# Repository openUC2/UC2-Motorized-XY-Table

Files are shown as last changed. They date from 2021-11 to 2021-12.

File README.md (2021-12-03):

<p align="left">

</p>

# openUC2 *Motorized XY Table*
---

__keywords__: Stepper motors, Arduino, Python, Freecad, 3D printing

The goal of this project is to convert a manual microscope stage into a motorized one that can be used with the UC2 system.
The stage is controlled through a common GRBL (i.e. 3D printer/CNC) interface and also integrates into the [ImSwitch](https://github.com/beniroquai/ImSwitch/tree/master/imswitch) software to control complex microscopy setups.
The precision of displacement approaches the micrometer. 
This repo is a fork from the [SonyCSLParis](https://github.com/SonyCSLParis/Motorized-stage) group.

Curious to see what this looks like? Keep scrolling!

<p align="center">
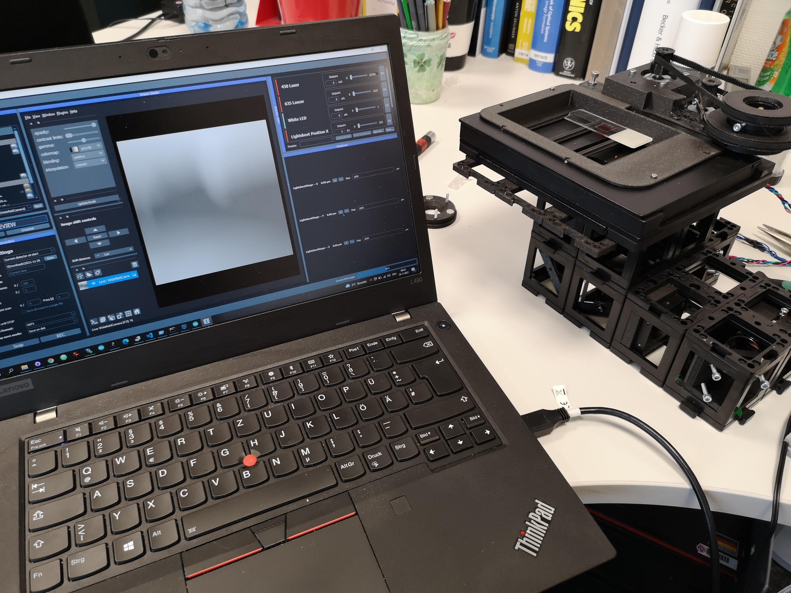
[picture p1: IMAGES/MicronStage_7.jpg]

</p>

All necessary parts besides the motors and the stage can be 3D printed. The overall price is ~200€.

***Features:***

The knobs initially used to manually move the platform are linked to motors via 2 belt-pulley systems (X and Y displacements). One removable part of the platform is replaced by a 3D-printed part that allows to fix the two motors. The pulleys are also 3D-printed to fit on the knobs. 

* Interact with it using GRBL/GCode
* large-scale microscopy slide scanning 
* easy to build 
* simple to automate 
* 

## In-Action

*The stage in action.*

<p align="center">

</p>

# Software

The stage is drive by 2 NEMA 17 stepper motors. For this we use a simple Arduino + CNC Shield v3. We don't want to specify the correct usage of the code here as there are many tutorials for how to interact with stepper motors and Arduino through e.g. Python. A more in-depth tutorial can be found in our [UC2-Hi2 APP](https://github.com/openUC2/UC2-Hi2) that makes use of the Makerbase MKS board and a customized PYTHON Interface. 
If you need assistance, don't hesitate to reach out to us! 

# Hardware

Below we describe how the device can be build and assembled in order to replicate the whole system as shown in the rendering above. One needs additional parts that can be found in the core [openUC2 repository](https://github.com/bionanoimaging/UC2-GIT).

## Bill of material

Below you will find all components necessary to build this device

### 3D printing files

All these files need to be printed. We used a Prusa i3 MK3 using PLA Prusament (Galaxy Black) at layer height x.x mm and infill xx%.

All files can be found in the folder [STL]

<p align="center">
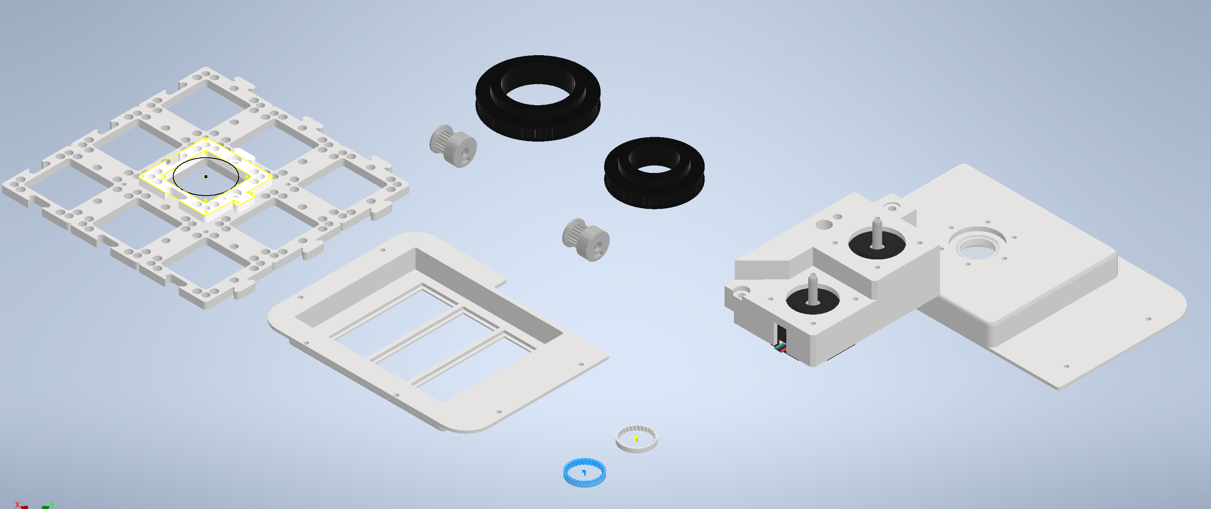
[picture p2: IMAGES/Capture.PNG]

</p>

|  Type | Details  |  Price | Link  | IMAGE |
|---|---|---|---|---|
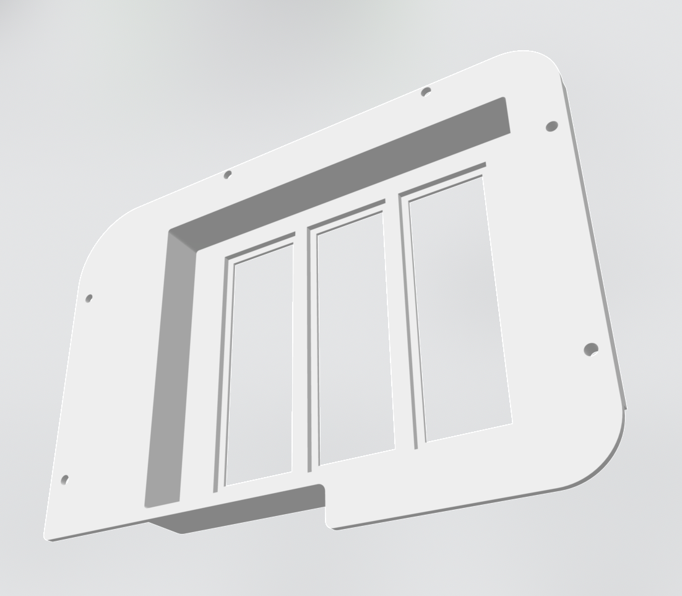
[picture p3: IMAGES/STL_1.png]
| Sample inset |  This can hold three standard sample slides |  1,00 € | [Part.stl](./STL/)  |   |
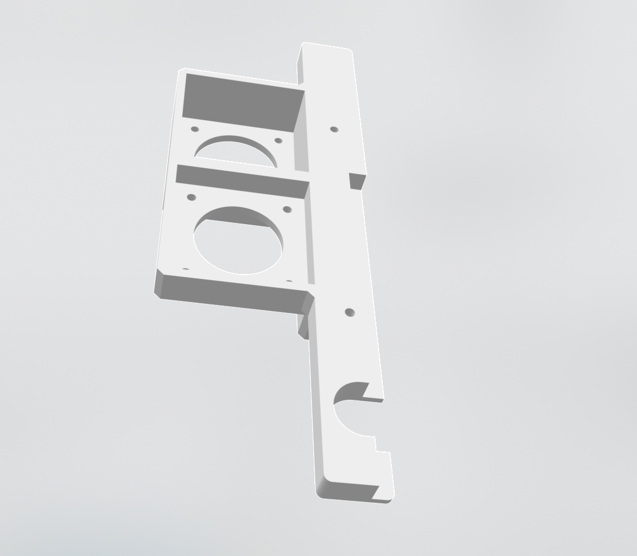
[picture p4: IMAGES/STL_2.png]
| Motor mount |  This holds the two NEMA 17 stepper motors |  1,00 € | [Part.stl](./STL/)  |   |
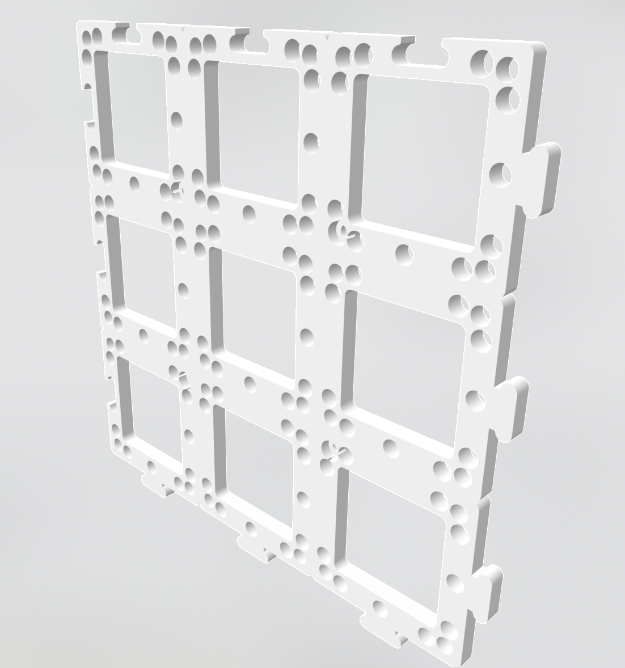
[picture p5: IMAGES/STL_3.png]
| UC2 mount |  This mounts the stage on the cubes |  1,00 € | [Part.stl](./STL/l)  |   |
| Gear Large | For the belt |  1,00 € | [Part.stl](./STL/)  | |
| Gear small |  For the belt |  1,00 € | [Part.stl](./STL/)  |  |
| 2x Pulley  |  For the belt |  1,00 € | [Part.stl](./STL/)  |  |

Fully assembled:
<p align="center">
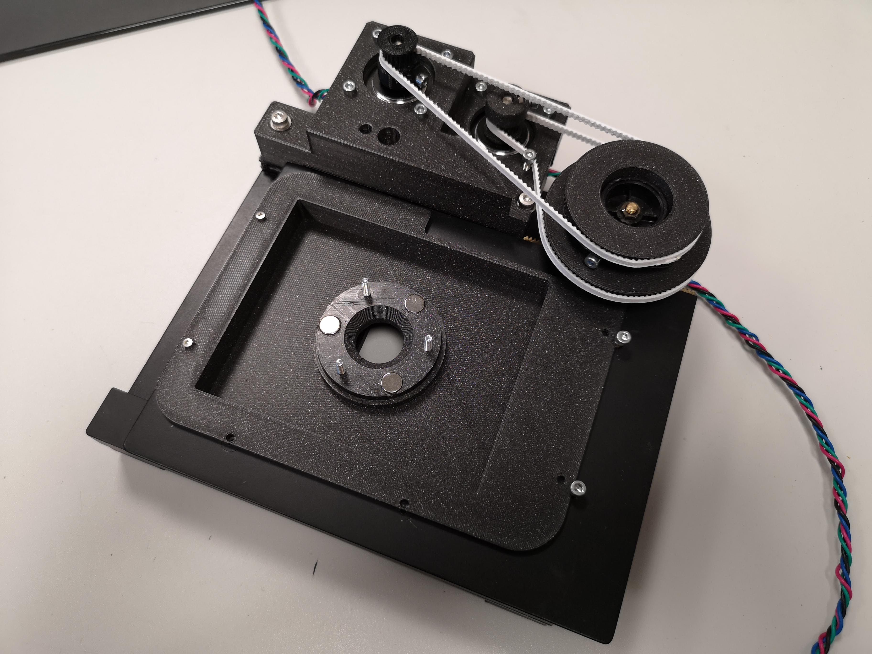
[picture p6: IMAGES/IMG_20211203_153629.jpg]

</p>

***OPTIONAL***: The GT2 timing belts can be printed using TPU/ninjaflex material.

### Additional parts
This is used in the current version of the setup

|  Type | Details  |  Price | Link  |
|---|---|---|---|
| Microscopy XY table |  |  55€ + Shiping  | [Aliexpress](https://de.aliexpress.com/item/32850719102.html)  |
| Microscopy XY table (German Alternative) |  |  255€ + Shiping  | [Optik Pro](https://www.optik-pro.de/fuer-stereomikroskope/euromex-xy-tisch-dz-9020-185x145mm-dz-reihe/p,47040)  |
| 2x Pancake NEMA 17 motors  |  9€ + Shiping  | [Ebay](https://www.ebay.de/itm/392553834244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)  |
| Motor belt GT2 |2 |1€|[Phidgets](https://www.phidgets.com/?tier=2&catid=42&pcid=35) |
| Motor pulley 20 teeth/5mm bore |2 | 1€ |[Phidgets](https://www.phidgets.com/?tier=2&catid=42&pcid=35) | |
| Arduino + CNC Shield v3 + A4988 Drivers + 12 V supply  |2 | 20€ |[roboterbausatz.de]() | |
| Connection wires | | |  
| Screws M2, M3 | | |  
| 3D printer |

### Design files

All files are in the [INVENTOR](./INVENTOR) folder.

### Assembly of the DEVICE

***1.*** *Remove the ring on the bottom surface (some screws) and add the UC2 baseplate adapter with M3 screws*

<p align="center">
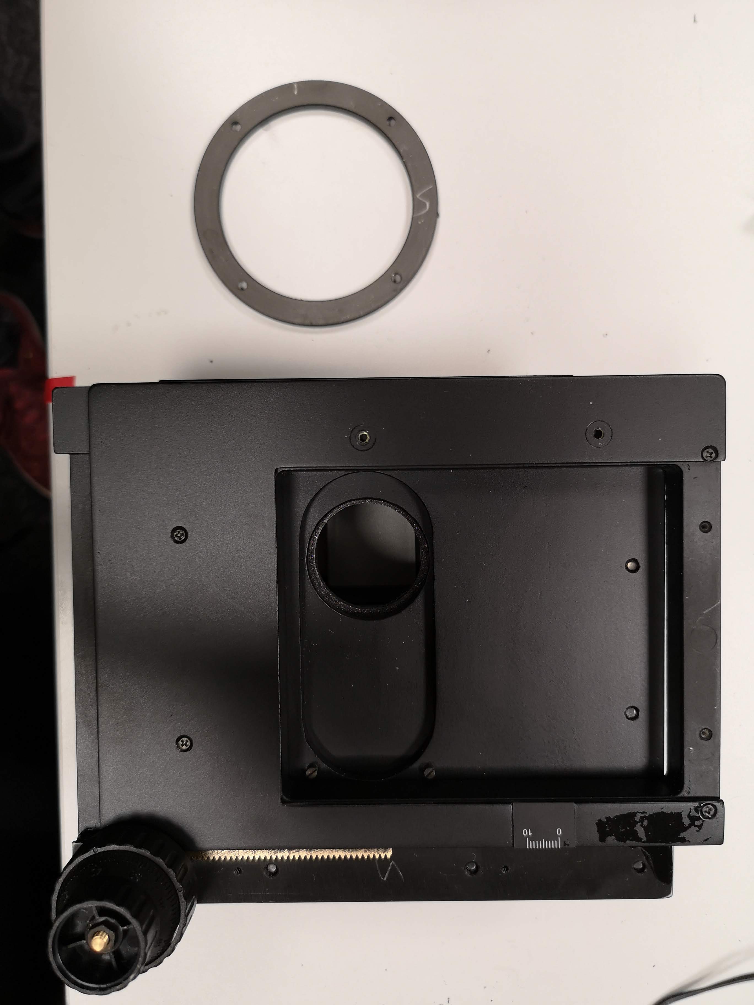
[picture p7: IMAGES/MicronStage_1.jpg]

</p>

<p align="center">
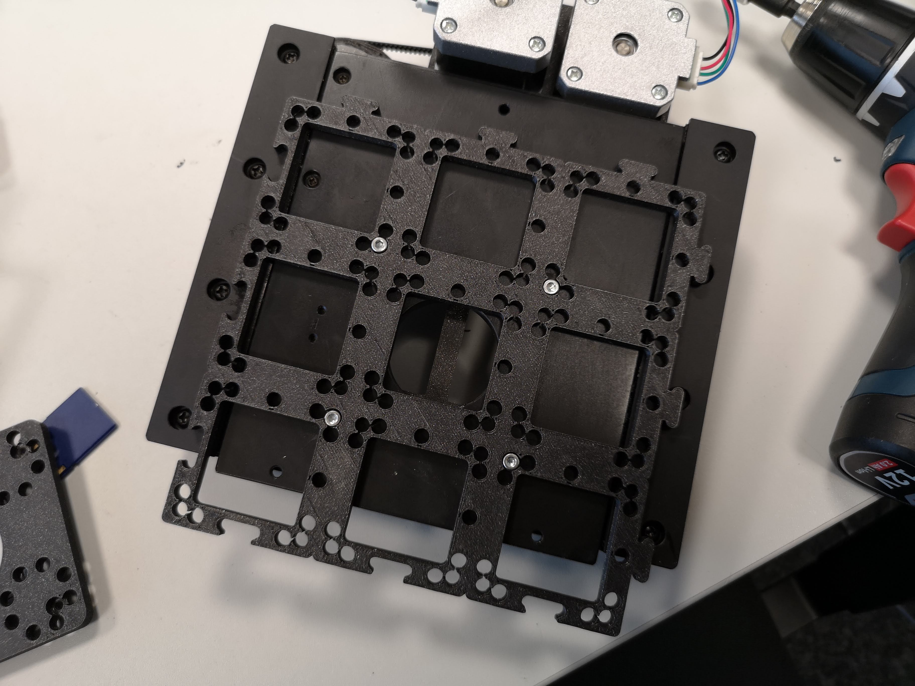
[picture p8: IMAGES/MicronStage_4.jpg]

</p>

***2.*** *Remove the stickers for the markers and unscrew the metal bar*

<p align="center">
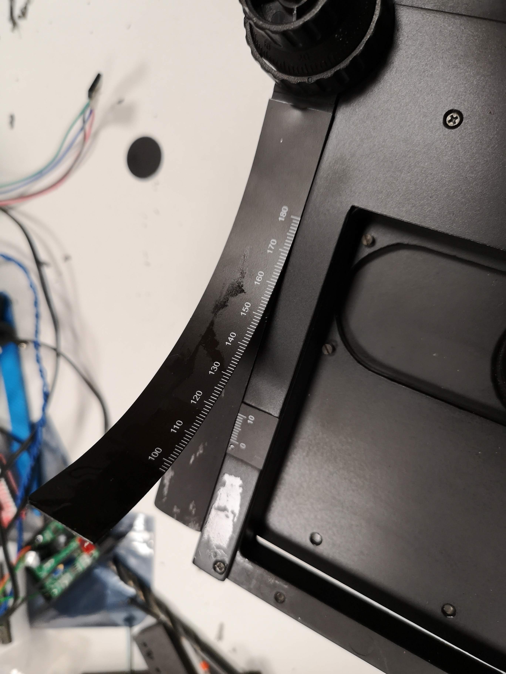
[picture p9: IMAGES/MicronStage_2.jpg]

</p>

<p align="center">
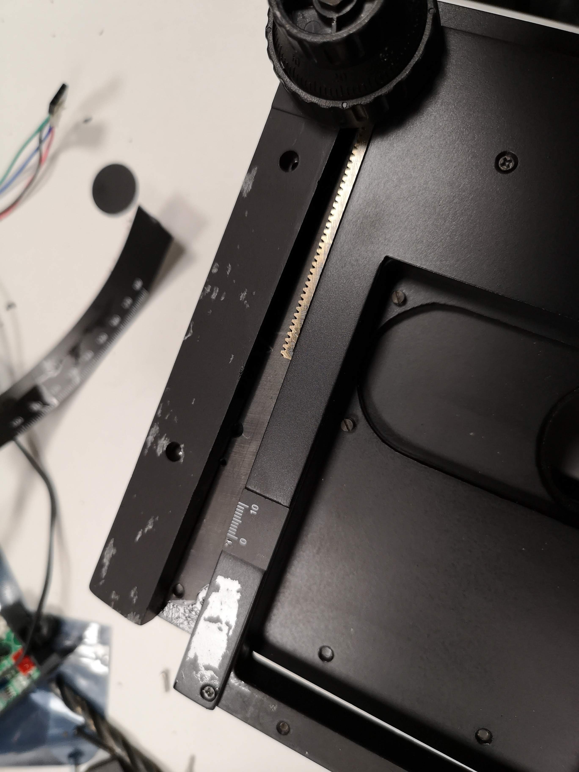
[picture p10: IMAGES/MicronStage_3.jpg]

</p>

***3.*** *Add the motors to the motor holder with M3 screws*

***PICTURES MISSING***

***4.*** *Add motor bar to the stage with M2 and M3 screws*

***PICTURES MISSING***

***5.*** *Add gears to motors and knobs*

***PICTURES MISSING***

***6.*** *Cut the belt and glue ends together to match the length properly using fast glue*

<p align="center">
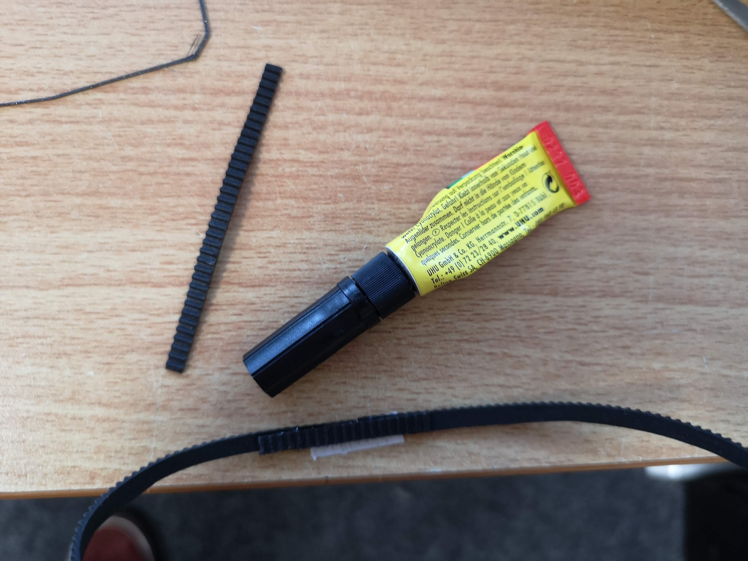
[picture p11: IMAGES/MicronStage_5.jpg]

</p>

***7.*** *Done*

<p align="center">
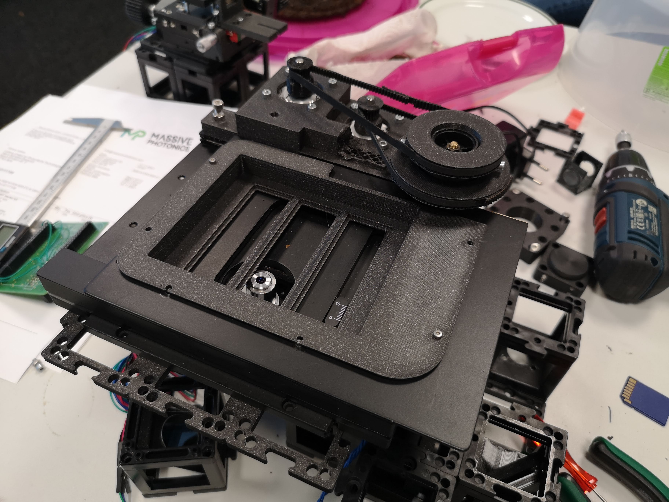
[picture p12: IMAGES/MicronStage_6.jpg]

</p>

## Showcase

Automation of a manual microscope stage

<p align="center">
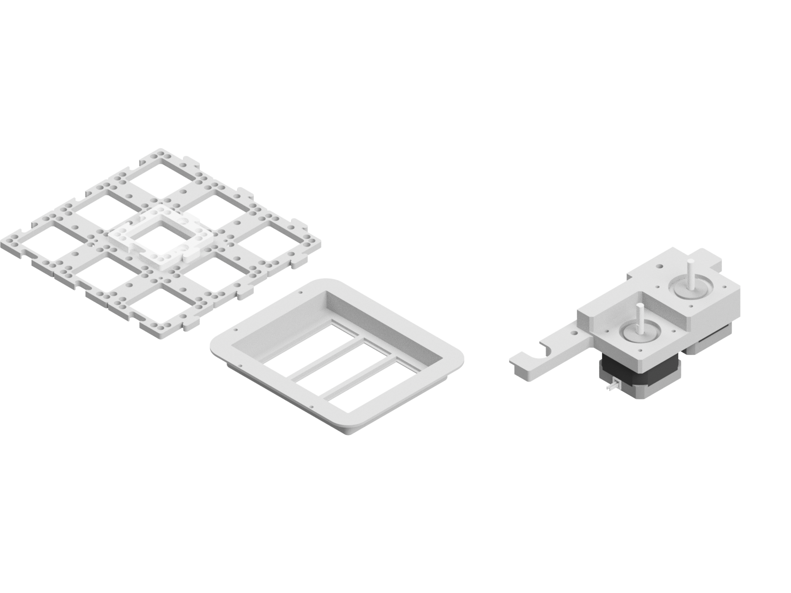
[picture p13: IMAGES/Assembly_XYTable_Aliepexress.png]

</p>

## Get Involved

This project is open so that anyone can get involved. You don't even have to learn CAD designing or programming. Find ways you can contribute in  [CONTRIBUTING](https://github.com/openUC2/UC2-GIT/blob/master/CONTRIBUTING.md)

## License and Collaboration

This project is open-source and is released under the CERN open hardware license. Our aim is to make the kits commercially available.
We encourage everyone who is using our Toolbox to share their results and ideas, so that the Toolbox keeps improving. It should serve as a easy-to-use and easy-to-access general purpose building block solution for the area of STEAM education. All the design files are generally for free, but we would like to hear from you how is it going.

You're free to fork the project and enhance it. If you have any suggestions to improve it or add any additional functions make a pull-request or file an issue.

Please find the type of licenses [here](https://github.com/openUC2/UC2-GIT/blob/master/License.md)

REMARK: All files have been designed using Autodesk Inventor 2019 (EDUCATION)

## Collaborating
If you find this project useful, please like this repository, follow us on Twitter and cite the webpage! :-)

-------

***FROM THE ORIGINAL FORK:***

# Results 

In the end we were able to control the movement of the stage to go from one trap to the following one. The following animation shows a trap and its neighbour appearing one after the other in the center of the camera.

<p align="center">

</p>

<p align="center">
Credits: Léa Pinon and Jacques Fattacioli for the microfluidic set-up (ENS, IPGG), Thomas Le Saux and Aliénor Lahlou for the imaging set-up (ENS, Sony CSL)
</p>  

By using the EasyDriver we could rotate each motor by one microstep. In the end the set-up enabled us to reach a minimal movement of 1,95 μm along the **x** axis and of 0,05 μm along the **y** axis.

In order to estimate the quality of our set-up, we measured its precision using the registration method which calculates the spatial correlation between two successive IMAGES.

On the one hand the analyses of these results shows that the stage moves linearly along the **y** axis as expected. We concluded that our set-up was of good quality for this direction.

<p align="center">

</p>

On the other hand we discovered that the movement along the **x** axis is flawed. Indeed when moving the stage along this axis we regularly measure a small unwanted movement along the **y** axis. This shortcoming leads to imprecise movement along the **x** axis, and it seems to come from the mechanics of the manual platform.

<p align="center">

</p>

For the **x**-axis we measured that one turn of the knob moves the stage by 2,5 cm. In the case of the **x** axis the 17HM08-1204S stepper motor has 3200 microsteps per revolution and the master pulley has 20 teeth. Thus we calculated that the **x**-axis slave pulley needed to have 32 teeth. Such a little number of teeth leads to modeling issues.

Thus we decided to design an 80 teeth slave pulley for the **x**-axis knob. This leads to a higher precision : when the stepper motor rotates by 1 microstep, the stage moves by 1,95 μm along the **x** axis (with a simple Nema 17 motor)

## Assembly

In order to keep things simple we decided to control both stepper motors with one Arduino UNO microcontroller. We still had to use one EasyDriver microcontroller for each stepper motor. We used [Brian Schmalzhaus' example](https://www.schmalzhaus.com/EasyDriver/Examples/EasyDriverExamples.html) running multiple stepper motors. The set-up can be seen in the following diagram. As we wanted precise movements, we enabled microstepping control for both motors by adding connections between the MS1 and MS2 pins and the ground for each EasyDriver microcontroller.

<p align="center">
<img src="IMAGES/image_from_schmalzhaus.png" width=500"/>
</p>  

<p align="center">
<a href=https://www.schmalzhaus.com/EasyDriver/Examples/EasyDriverExamples.html>source</a>
</p>  

## License

This project is licensed under the [GNU General Public License v3.0](https://tldrlegal.com/license/gnu-general-public-license-v3-(gpl-3))

## Contacts
If you have questions you can contact Ali Ruyer-Thompson (ali.ruyer--thompson :email: ens.psl.eu) or Aliénor Lahlou (alienor.lahlou :email: ens.psl.eu)

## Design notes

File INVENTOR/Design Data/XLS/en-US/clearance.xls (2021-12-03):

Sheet: Ansi Unified Screw Threads
I | Sort Order -1
Fastener Type | Size | Shaft Diameters |  |  | Head Dimensions
 |  | Close | Normal | Loose | Diameter | Depth/Angle | Head Type
Flat Head Machine Screw (82) | #0 | 0.0635 | 0.07 | 0.073 | 0.119 | 82 | 2
Flat Head Machine Screw (82) | #1 | 0.076 | 0.081 | 0.089 | 0.146 | 82 | 2
Flat Head Machine Screw (82) | #2 | 0.089 | 0.096 | 0.1065 | 0.172 | 82 | 2
Flat Head Machine Screw (82) | #3 | 0.104 | 0.11 | 0.12 | 0.199 | 82 | 2
Flat Head Machine Screw (82) | #4 | 0.116 | 0.1285 | 0.136 | 0.225 | 82 | 2
Flat Head Machine Screw (82) | #5 | 0.1285 | 0.136 | 0.154 | 0.252 | 82 | 2
Flat Head Machine Screw (82) | #6 | 0.144 | 0.1495 | 0.1695 | 0.279 | 82 | 2
Flat Head Machine Screw (82) | #8 | 0.1695 | 0.177 | 0.1935 | 0.332 | 82 | 2
Flat Head Machine Screw (82) | #10 | 0.196 | 0.201 | 0.221 | 0.385 | 82 | 2
Flat Head Machine Screw (82) | #12 | 0.221 | 0.228 | 0.246 | 0.438 | 82 | 2
Flat Head Machine Screw (82) | 1/4 | 0.257 | 0.266 | 0.2812 | 0.507 | 82 | 2
Flat Head Machine Screw (82) | 5/16 | 0.323 | 0.332 | 0.3437 | 0.635 | 82 | 2
Flat Head Machine Screw (82) | 3/8 | 0.386 | 0.397 | 0.4062 | 0.762 | 82 | 2
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

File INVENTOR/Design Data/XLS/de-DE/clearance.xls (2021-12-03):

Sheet: ANSI UST
I | Reihenfolge -1
Schraubentyp | Größe | Wellendurchmesser |  |  | Schraubenkopfbemaßungen
 |  | Schließen | Normal | Grob | Durchmesser | Tiefe/Winkel | Schraubenkopftyp
Flachkopfmaschinenschraube (82) | #0 | 0.0635 | 0.07 | 0.073 | 0.119 | 82 | 2
Flachkopfmaschinenschraube (82) | #1 | 0.076 | 0.081 | 0.089 | 0.146 | 82 | 2
Flachkopfmaschinenschraube (82) | #2 | 0.089 | 0.096 | 0.1065 | 0.172 | 82 | 2
Flachkopfmaschinenschraube (82) | #3 | 0.104 | 0.11 | 0.12 | 0.199 | 82 | 2
Flachkopfmaschinenschraube (82) | #4 | 0.116 | 0.1285 | 0.136 | 0.225 | 82 | 2
Flachkopfmaschinenschraube (82) | #5 | 0.1285 | 0.136 | 0.154 | 0.252 | 82 | 2
Flachkopfmaschinenschraube (82) | #6 | 0.144 | 0.1495 | 0.1695 | 0.279 | 82 | 2
Flachkopfmaschinenschraube (82) | #8 | 0.1695 | 0.177 | 0.1935 | 0.332 | 82 | 2
Flachkopfmaschinenschraube (82) | #10 | 0.196 | 0.201 | 0.221 | 0.385 | 82 | 2
Flachkopfmaschinenschraube (82) | #12 | 0.221 | 0.228 | 0.246 | 0.438 | 82 | 2
Flachkopfmaschinenschraube (82) | 1/4 | 0.257 | 0.266 | 0.2812 | 0.507 | 82 | 2
Flachkopfmaschinenschraube (82) | 5/16 | 0.323 | 0.332 | 0.3437 | 0.635 | 82 | 2
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

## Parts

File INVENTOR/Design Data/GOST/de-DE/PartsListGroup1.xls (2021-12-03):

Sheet: Лист 1
Инв. № подл |  |  |  | Подп. и дата | Взам. инв. № | Инв. № дубл. |  |  | Подп. и дата
Формат | Зона | Поз. | Обозначение |  |  |  | Наименование |  |  |  |  |  | Кол. на исполнение
 |  |  |  |  |  |  |  |  |  |  |  | Лит.
 |  |  |  |  |  |  |  |  |  |  |  | Код
 |  |  |  |  |  |  |  | Изм. | Лист | № докум | Подпись |  | Дата
 |  |  |  |  |  |  |  | Разраб.
 |  |  |  |  |  |  |  | Пров.
 |  |  |  |  |  |  |  | Н.контр
 |  |  |  |  |  |  |  | Утв.
 |  |  |  |  |  |  |  |  |  |  |  |  |  | Копировал

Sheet: Лист 2
Инв. № подл |  |  |  | Подп. и дата | Взам. инв. № | Инв. № дубл. |  |  | Подп. и дата
Формат | Зона | Поз. | Обозначение |  |  |  | Наименование |  |  |  |  | Кол. на исполнение
 |  |  |  |  |  |  |  | Изм. | Лист | № докум. | Подп. | Дата
 |  |  |  |  |  |  |  |  |  |  |  |  | Копировал
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

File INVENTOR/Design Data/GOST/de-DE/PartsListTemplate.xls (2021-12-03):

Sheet: Лист 1
 | Формат | Зона |  | Поз. |  | Обозначение |  |  |  | Наименование |  |  |  | Кол. | Приме-чание
Подп. и дата
Инв. № дубл.
Взам. инв. №
Подп. и дата
 | Изм. |  | Лист |  | № докум |  | Подпись | Дата
Инв. № подл | Разраб. |  |  |  |  |  |  |  |  |  | Литера |  | Лист |  |  | Листов
 | Пров.
 | Н.контр
 | Утв.
 |  |  |  |  |  |  |  |  | Копировал |  |  | Формат А4

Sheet: Лист 2
 | Формат | Зона |  | Поз. |  | Обозначение |  |  |  | Наименование |  | Кол. | Приме-чание
Подп. и дата
Инв. № дубл.
Взам. инв. №
Подп. и дата
Инв. № подл
 | Изм. |  | Лист |  | № докум. |  | Подп. |  | Дата
 |  |  |  |  |  |  |  | Копировал |  |  | Формат А4
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

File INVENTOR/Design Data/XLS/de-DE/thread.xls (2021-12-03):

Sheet: Inch Tapping Threads
I Q X | Zoll-Blechschraubgewinde |  | Sort Order - 5 |  | External |  |  |  |  |  |  | Internal
 |  |  |  |  |  | Major Dia |  | Pitch Dia |  | Minor Dia |  |  | Minor Dia |  | Pitch Dia |  | Major Dia |  | Tap Drill
Size | Size Suffix | Thread Designation | Custom Thread Designation | TPI | Class | Max | Min | Max | Min | Max | Min | Class | Min | Max | Min | Max | Min | Max | Basic
0.0600 |  | 0-48 | 0-48 | 48 | 2B | 0.0600 | 0.0540 | 0.0480 | 0.0435 | 0.0360 | 0.0330
0.0730 |  | 1-42 | 1-42 | 42 | 2B | 0.0750 | 0.0690 | 0.0620 | 0.0575 | 0.0490 | 0.0460
0.0860 |  | 2-32 | 2-32 | 32 | 2B | 0.0880 | 0.0820 | 0.0760 | 0.0710 | 0.0640 | 0.0600
0.0990 |  | 3-28 | 3-28 | 28 | 2B | 0.1010 | 0.0950 | 0.0880 | 0.0830 | 0.0750 | 0.0710
0.1120 |  | 4-24 | 4-24 | 24 | 2B | 0.1140 | 0.1080 | 0.1000 | 0.0950 | 0.0860 | 0.0820
0.1250 |  | 5-20 | 5-20 | 20 | 2B | 0.1300 | 0.1230 | 0.1120 | 0.1065 | 0.0940 | 0.0900
0.1380 |  | 6-20 | 6-20 | 20 | 2B | 0.1390 | 0.1320 | 0.1215 | 0.1155 | 0.1040 | 0.0990
0.1510 |  | 7-19 | 7-19 | 19 | 2B | 0.1540 | 0.1470 | 0.1345 | 0.1280 | 0.1150 | 0.1090
0.1640 |  | 8-18 | 8-18 | 18 | 2B | 0.1660 | 0.1590 | 0.1440 | 0.1375 | 0.1220 | 0.1160
0.1900 |  | 10-16 | 10-16 | 16 | 2B | 0.1890 | 0.1820 | 0.1650 | 0.1585 | 0.1410 | 0.1350
0.2160 |  | 12-14 | 12-14 | 14 | 2B | 0.2150 | 0.2080 | 0.1895 | 0.1825 | 0.1640 | 0.1570
0.2420 |  | 14-14 | 14-14 | 14 | 2B | 0.2410 | 0.2340 | 0.2130 | 0.2060 | 0.1850 | 0.1780
0.2500 |  | 1/4-14 | 1/4-14 | 14 | 2B | 0.2460 | 0.2370 | 0.2190 | 0.2110 | 0.1920 | 0.1850
0.3125 |  | 5/16-12 | 5/16-12 | 12 | 2B | 0.3150 | 0.3060 | 0.2795 | 0.2710 | 0.2440 | 0.2360
0.3750 |  | 3/8-12 | 3/8-12 | 12 | 2B | 0.3800 | 0.3710 | 0.3445 | 0.3350 | 0.3090 | 0.2990
0.4375 |  | 7/16-10 | 7/16-10 | 10 | 2B | 0.4400 | 0.4290 | 0.3995 | 0.3890 | 0.3590 | 0.3490
0.5000 |  | 1/2-10 | 1/2-10 | 10 | 2B | 0.5040 | 0.4930 | 0.4635 | 0.4530 | 0.4230 | 0.4130

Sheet: Metric Forming Screw Threads
M P X | Metrisch geform. Schraubgewinde |  | Sort Order - 6 |  | External |  |  |  |  |  |  | Internal
 |  |  |  |  |  | Major Dia |  | Pitch Dia |  | Minor Dia |  |  | Minor Dia |  | Pitch Dia |  | Major Dia |  | Tap Drill
Size | Size Suffix | Thread Designation | Custom Thread Designation | Pitch | Class | Max | Min | Max | Min | Max | Min | Class | Min | Max | Min | Max | Min | Max | Basic
1.5 |  | 1.5x0.5 | 1.5x0.5 | 0.5 | 6g | 1.520 | 1.380 | 1.215 | 1.110 | 0.910 | 0.840
1.5 |  | ST1.5x0.5 | ST1.5x0.5 | 0.5 | 6g | 1.520 | 1.380 | 1.215 | 1.110 | 0.910 | 0.840
1.9 |  | 1.9x0.6 | 1.9x0.6 | 0.6 | 6g | 1.900 | 1.760 | 1.570 | 1.465 | 1.240 | 1.170
1.9 |  | ST1.9x0.6 | ST1.9x0.6 | 0.6 | 6g | 1.900 | 1.760 | 1.570 | 1.465 | 1.240 | 1.170
2.2 |  | 2.2x0.8 | 2.2x0.8 | 0.8 | 6g | 2.240 | 2.100 | 1.935 | 1.810 | 1.630 | 1.520
2.2 |  | ST2.2x0.8 | ST2.2x0.8 | 0.8 | 6g | 2.240 | 2.100 | 1.935 | 1.810 | 1.630 | 1.520
2.6 |  | 2.6x0.9 | 2.6x0.9 | 0.9 | 6g | 2.570 | 2.430 | 2.235 | 2.115 | 1.900 | 1.800
2.6 |  | ST2.6x0.9 | ST2.6x0.9 | 0.9 | 6g | 2.570 | 2.430 | 2.235 | 2.115 | 1.900 | 1.800
2.9 |  | 2.9x1 | 2.9x1 | 1 | 6g | 2.900 | 2.760 | 2.540 | 2.420 | 2.180 | 2.080
2.9 |  | 2.9x1.1 | 2.9x1.1 | 1.1 | 6g | 2.900 | 2.760 | 2.540 | 2.420 | 2.180 | 2.080
2.9 |  | ST2.9x1.1 | ST2.9x1.1 | 1.1 | 6g | 2.900 | 2.760 | 2.540 | 2.420 | 2.180 | 2.080
2.9 |  | 2.9x1.3 | 2.9x1.3 | 1.3 | 6g | 2.900 | 2.720 | 2.540 | 2.355 | 1.890 | 1.700
2.9 |  | 2.9x1.4 | 2.9x1.4 | 1.4 | 6g | 2.900 | 2.720 | 2.340 | 2.175 | 1.780 | 1.630
3.3 |  | 3.3x1.3 | 3.3x1.3 | 1.3 | 6g | 3.300 | 3.120 | 2.795 | 2.665 | 2.290 | 2.210
3.3 |  | ST3.3x1.3 | ST3.3x1.3 | 1.3 | 6g | 3.300 | 3.120 | 2.795 | 2.665 | 2.290 | 2.210
3.5 |  | 3.5x1.3 | 3.5x1.3 | 1.3 | 6g | 3.530 | 3.350 | 3.085 | 2.930 | 2.640 | 2.510
3.5 |  | ST3.5x1.3 | ST3.5x1.3 | 1.3 | 6g | 3.530 | 3.350 | 3.085 | 2.930 | 2.640 | 2.510
3.5 |  | 3.5x1.6 | 3.5x1.6 | 1.6 | 6g | 3.530 | 3.350 | 2.920 | 2.755 | 2.310 | 2.160
3.5 |  | 3.5x3.2 | 3.5x3.2 | 3.2 | 6g | 3.530 | 3.310 | 2.800 | 2.600 | 2.070 | 1.890
3.9 |  | 3.9x1.3 | 3.9x1.3 | 1.3 | 6g | 3.910 | 3.730 | 3.415 | 3.250 | 2.920 | 2.770
3.9 |  | ST3.9x1.3 | ST3.9x1.3 | 1.3 | 6g | 3.910 | 3.730 | 3.415 | 3.250 | 2.920 | 2.770
3.9 |  | 3.9x1.6 | 3.9x1.6 | 1.6 | 6g | 3.910 | 3.730 | 3.300 | 3.135 | 2.690 | 2.540
3.9 |  | 3.9x3.2 | 3.9x3.2 | 3.2 | 6g | 3.910 | 3.690 | 3.180 | 2.980 | 2.450 | 2.270
4.2 |  | 4.2x1.4 | 4.2x1.4 | 1.4 | 6g | 4.220 | 4.040 | 3.660 | 3.495 | 3.100 | 2.950
4.2 |  | ST4.2x1.4 | ST4.2x1.4 | 1.4 | 6g | 4.220 | 4.040 | 3.660 | 3.495 | 3.100 | 2.950
4.2 |  | 4.2x1.6 | 4.2x1.6 | 1.6 | 6g | 4.220 | 4.040 | 3.610 | 3.445 | 3.000 | 2.850
4.2 |  | 4.2x3.2 | 4.2x3.2 | 3.2 | 6g | 4.220 | 4.000 | 3.380 | 3.180 | 2.540 | 2.360
4.8 |  | 4.8x1.6 | 4.8x1.6 | 1.6 | 6g | 4.800 | 4.620 | 4.190 | 4.025 | 3.580 | 3.430
4.8 |  | ST4.8x1.6 | ST4.8x1.6 | 1.6 | 6g | 4.800 | 4.620 | 4.190 | 4.025 | 3.580 | 3.430
4.8 |  | 4.8x1.8 | 4.8x1.8 | 1.8 | 6g | 4.800 | 4.620 | 4.065 | 3.885 | 3.330 | 3.150
4.8 |  | 4.8x3.2 | 4.8x3.2 | 3.2 | 6g | 4.800 | 4.580 | 3.960 | 3.760 | 3.120 | 2.940
5.5 |  | 5.5x1.8 | 5.5x1.8 | 1.8 | 6g | 5.460 | 5.280 | 4.815 | 4.635 | 4.170 | 3.990
5.5 |  | ST5.5x1.8 | ST5.5x1.8 | 1.8 | 6g | 5.460 | 5.280 | 4.815 | 4.635 | 4.170 | 3.990
6.3 |  | 6.3x1.8 | 6.3x1.8 | 1.8 | 6g | 6.250 | 6.030 | 5.565 | 5.365 | 4.880 | 4.700
6.3 |  | ST6.3x1.8 | ST6.3x1.8 | 1.8 | 6g | 6.250 | 6.030 | 5.565 | 5.365 | 4.880 | 4.700
8.0 |  | 8x2.1 | 8x2.1 | 2.1 | 6g | 8.000 | 7.780 | 7.100 | 6.885 | 6.200 | 5.990
8.0 |  | ST8x2.1 | ST8x2.1 | 2.1 | 6g | 8.000 | 7.780 | 7.100 | 6.885 | 6.200 | 5.990
9.5 |  | 9.5x2.1 | 9.5x2.1 | 2.1 | 6g | 9.650 | 9.430 | 8.750 | 8.510 | 7.850 | 7.590
9.5 |  | ST9.5x2.1 | ST9.5x2.1 | 2.1 | 6g | 9.650 | 9.430 | 8.750 | 8.510 | 7.850 | 7.590

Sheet: ISO Pipe Threads
M Q | ISO-Rohrgewinde |  | Sort Order - 9 |  | External |  |  |  |  |  |  | Internal
 |  |  |  |  |  | Major Dia |  | Pitch Dia |  | Minor Dia |  |  | Minor Dia |  | Pitch Dia |  | Major Dia |  | Tap Drill | Thread Depth | Thread Runouts
Size | Size Suffix | Thread Designation | Custom Thread Designation | TPI | Class | Max | Min | Max | Min | Max | Min | Class | Min | Max | Min | Max | Min | Max | Basic
7.723 |  | G7.723x0.907 | G 1/16 | 28 | A | 7.723 | 7.509 | 7.142 | 7.035 | 6.561 |  |  | 6.561 | 6.834 | 7.142 | 7.249 | 7.723 |  | 1.5875 | 15.446 | 4.5000
7.723 |  | G7.723x0.907 | G 1/16 | 28 | B | 7.723 | 7.509 | 7.142 | 6.928 | 6.561
9.728 |  | G9.728x0.907 | G 1/8 | 28 | A | 9.728 | 9.514 | 9.147 | 9.040 | 8.566 |  |  | 8.566 | 8.848 | 9.147 | 9.254 | 9.728 |  | 3.1750 | 19.456 | 4.5000
9.728 |  | G9.728x0.907 | G 1/8 | 28 | B | 9.728 | 9.514 | 9.147 | 8.933 | 8.566
13.157 |  | G13.157x1.337 | G 1/4 | 19 | A | 13.157 | 12.907 | 12.301 | 12.176 | 11.445 |  |  | 11.445 | 11.89 | 12.301 | 12.426 | 13.157 |  | 6.3500 | 26.314 | 6.5000
13.157 |  | G13.157x1.337 | G 1/4 | 19 | B | 13.157 | 12.907 | 12.301 | 12.051 | 11.445
16.662 |  | G16.662x1.337 | G 3/8 | 19 | A | 16.662 | 16.412 | 15.806 | 15.681 | 14.950 |  |  | 14.95 | 15.395 | 15.806 | 15.931 | 16.662 |  | 9.5250 | 33.324 | 6.5000
16.662 |  | G16.662x1.337 | G 3/8 | 19 | B | 16.662 | 16.412 | 15.806 | 15.556 | 14.950
20.955 |  | G20.955x1.814 | G 1/2 | 14 | A | 20.955 | 20.671 | 19.793 | 19.651 | 18.631 |  |  | 18.631 | 19.172 | 19.793 | 19.935 | 20.955 |  | 12.7000 | 41.910 | 8.5000
20.955 |  | G20.955x1.814 | G 1/2 | 14 | B | 20.955 | 20.671 | 19.793 | 19.509 | 18.631
22.911 |  | G22.911x1.814 | G 5/8 | 14 | A | 22.911 | 22.627 | 21.749 | 21.607 | 20.587 |  |  | 20.587 | 21.128 | 21.749 | 21.891 | 22.911 |  |  | 45.822 | 8.5000
22.911 |  | G22.911x1.814 | G 5/8 | 14 | B | 22.911 | 22.627 | 21.749 | 21.465 | 20.587
26.441 |  | G26.441x1.814 | G 3/4 | 14 | A | 26.441 | 26.157 | 25.279 | 25.137 | 24.117 |  |  | 24.117 | 24.658 | 25.279 | 25.421 | 26.441 |  | 15.8750 | 52.882 | 8.5000
26.441 |  | G26.441x1.814 | G 3/4 | 14 | B | 26.441 | 26.157 | 25.279 | 24.995 | 24.117
30.201 |  | G30.201x1.814 | G 7/8 | 14 | A | 30.201 | 29.917 | 29.039 | 28.897 | 27.877 |  |  | 27.877 | 28.418 | 29.039 | 29.181 | 30.201 |  | 22.2250 | 60.402 | 8.5000
30.201 |  | G30.201x1.814 | G 7/8 | 14 | B | 30.201 | 29.917 | 29.039 | 28.755 | 27.877
33.249 |  | G33.249x2.309 | G 1 | 11 | A | 33.249 | 32.889 | 31.770 | 31.590 | 30.291 |  |  | 30.291 | 30.931 | 31.77 | 31.95 | 33.249 |  | 25.4000 | 66.498 | 10.0000
33.249 |  | G33.249x2.309 | G 1 | 11 | B | 33.249 | 32.889 | 31.770 | 31.410 | 30.291
37.897 |  | G37.897x2.309 | G 1 1/8 | 11 | A | 37.897 | 37.537 | 36.418 | 36.238 | 34.939 |  |  | 34.939 | 35.579 | 36.418 | 36.598 | 37.897 |  | 28.5750 | 75.794 | 10.0000
37.897 |  | G37.897x2.309 | G 1 1/8 | 11 | B | 37.897 | 37.537 | 36.418 | 36.058 | 34.939
41.910 |  | G41.91x2.309 | G 1 1/4 | 11 | A | 41.910 | 41.550 | 40.431 | 40.251 | 38.952 |  |  | 38.952 | 39.592 | 40.431 | 40.611 | 41.910 |  | 31.7500 | 83.820 | 10.0000
41.910 |  | G41.91x2.309 | G 1 1/4 | 11 | B | 41.910 | 41.550 | 40.431 | 40.071 | 38.952
47.803 |  | G47.803x2.309 | G 1 1/2 | 11 | A | 47.803 | 47.443 | 46.324 | 46.144 | 44.845 |  |  | 44.845 | 45.485 | 46.324 | 46.504 | 47.803 |  | 38.1000 | 95.606 | 10.0000
47.803 |  | G47.803x2.309 | G 1 1/2 | 11 | B | 47.803 | 47.443 | 46.324 | 45.964 | 44.845
53.746 |  | G53.746x2.309 | G 1 3/4 | 11 | A | 53.746 | 53.386 | 52.267 | 52.087 | 50.788 |  |  | 50.788 | 51.428 | 52.267 | 52.447 | 53.746 |  | 44.4500 | 107.492 | 10.0000
53.746 |  | G53.746x2.309 | G 1 3/4 | 11 | B | 53.746 | 53.386 | 52.267 | 51.907 | 50.788
59.614 |  | G59.614x2.309 | G 2 | 11 | A | 59.614 | 59.254 | 58.135 | 57.955 | 56.656 |  |  | 56.656 | 57.296 | 58.135 | 58.315 | 59.614 |  | 50.8000 | 119.228 | 10.0000
59.614 |  | G59.614x2.309 | G 2 | 11 | B | 59.614 | 59.254 | 58.135 | 57.775 | 56.656
65.710 |  | G65.71x2.309 | G 2 1/4 | 11 | A | 65.710 | 65.276 | 64.231 | 64.014 | 62.752 |  |  | 62.752 | 63.392 | 64.231 | 64.448 | 65.710 |  | 57.1500 | 131.420 | 10.0000
65.710 |  | G65.71x2.309 | G 2 1/4 | 11 | B | 65.710 | 65.276 | 64.231 | 63.797 | 62.752
75.184 |  | G75.184x2.309 | G 2 1/2 | 11 | A | 75.184 | 74.750 | 73.705 | 73.488 | 72.226 |  |  | 72.226 | 72.866 | 73.705 | 73.922 | 75.184 |  |  | 150.368 | 10.0000
75.184 |  | G75.184x2.309 | G 2 1/2 | 11 | B | 75.184 | 74.750 | 73.705 | 73.271 | 72.226
81.534 |  | G81.534x2.309 | G 2 3/4 | 11 | A | 81.534 | 81.100 | 80.055 | 79.838 | 78.576 |  |  | 78.576 | 79.216 | 80.055 | 80.272 | 81.534 |  | 69.8500 | 163.068 | 10.0000
81.534 |  | G81.534x2.309 | G 2 3/4 | 11 | B | 81.534 | 81.100 | 80.055 | 79.621 | 78.576
87.884 |  | G87.884x2.309 | G 3 | 11 | A | 87.884 | 87.450 | 86.405 | 86.188 | 84.926 |  |  | 84.926 | 85.566 | 86.405 | 86.622 | 87.884 |  | 76.2000 | 175.768 | 10.0000
87.884 |  | G87.884x2.309 | G 3 | 11 | B | 87.884 | 87.450 | 86.405 | 85.971 | 84.926
100.330 |  | G100.33x2.309 | G 3 1/2 | 11 | A | 100.330 | 99.896 | 98.851 | 98.634 | 97.372 |  |  | 97.372 | 98.012 | 98.851 | 99.068 | 100.330 |  | 88.9000 | 200.660 | 10.0000
100.330 |  | G100.33x2.309 | G 3 1/2 | 11 | B | 100.330 | 99.896 | 98.851 | 98.417 | 97.372
113.030 |  | G113.03x2.309 | G 4 | 11 | A | 113.030 | 112.596 | 111.551 | 111.334 | 110.072 |  |  | 110.072 | 110.712 | 111.551 | 111.768 | 113.030 |  | 101.6000 | 226.060 | 10.0000
113.030 |  | G113.03x2.309 | G 4 | 11 | B | 113.030 | 112.596 | 111.551 | 111.117 | 110.072
125.730 |  | G125.73x2.309 | G 4 1/2 | 11 | A | 125.730 | 125.296 | 124.251 | 124.034 | 122.772 |  |  | 122.772 | 123.412 | 124.251 | 124.468 | 125.730 |  | 114.3000 | 251.460 | 10.0000
125.730 |  | G125.73x2.309 | G 4 1/2 | 11 | B | 125.730 | 125.296 | 124.251 | 123.817 | 122.772
138.430 |  | G138.43x2.309 | G 5 | 11 | A | 138.430 | 137.996 | 136.951 | 136.734 | 135.472 |  |  | 135.472 | 136.112 | 136.951 | 137.168 | 138.430 |  | 127.0000 | 276.860 | 10.0000
138.430 |  | G138.43x2.309 | G 5 | 11 | B | 138.430 | 137.996 | 136.951 | 136.517 | 135.472
151.130 |  | G151.13x2.309 | G 5 1/2 | 11 | A | 151.130 | 150.696 | 149.651 | 149.434 | 148.172 |  |  | 148.172 | 148.812 | 149.651 | 149.868 | 151.130 |  | 139.7000 | 302.260 | 10.0000
151.130 |  | G151.13x2.309 | G 5 1/2 | 11 | B | 151.130 | 150.696 | 149.651 | 149.217 | 148.172
163.830 |  | G163.83x2.309 | G 6 | 11 | A | 163.830 | 163.396 | 162.351 | 162.134 | 160.872 |  |  | 160.872 | 161.512 | 162.351 | 162.568 | 163.830 |  | 152.4000 | 327.660 | 10.0000
163.830 |  | G163.83x2.309 | G 6 | 11 | B | 163.830 | 163.396 | 162.351 | 161.917 | 160.872

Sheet: JIS Pipe Threads
M Q | JIS-Rohrgewinde |  | Sort Order -12 |  | External |  |  |  |  |  |  | Internal
 |  |  |  |  |  | Major Dia |  | Pitch Dia |  | Minor Dia |  |  | Minor Dia |  | Pitch Dia |  | Major Dia |  | Tap Drill | Thread Depth | Thread Runouts
Size | Size Suffix | Thread Designation | Custom Thread Designation | TPI | Class | Max | Min | Max | Min | Max | Min | Class | Min | Max | Min | Max | Min | Max | Basic |  | Basic
7.723 |  | G7.723x0.907 | G 1/16 | 28 | A | 7.723 | 7.509 | 7.142 | 7.035 | 6.561 |  |  | 6.561 | 6.834 | 7.142 | 7.249 | 7.723 |  | 1.5875 | 15.446 | 4.5000
7.723 |  | G7.723x0.907 | G 1/16 | 28 | B | 7.723 | 7.509 | 7.142 | 6.928 | 6.561
9.728 |  | G9.728x0.907 | G 1/8 | 28 | A | 9.728 | 9.514 | 9.147 | 9.040 | 8.566 |  |  | 8.566 | 8.848 | 9.147 | 9.254 | 9.728 |  | 3.1750 | 19.456 | 4.5000
9.728 |  | G9.728x0.907 | G 1/8 | 28 | B | 9.728 | 9.514 | 9.147 | 8.933 | 8.566
13.157 |  | G13.157x1.337 | G 1/4 | 19 | A | 13.157 | 12.907 | 12.301 | 12.176 | 11.445 |  |  | 11.445 | 11.89 | 12.301 | 12.426 | 13.157 |  | 6.3500 | 26.314 | 6.5000
13.157 |  | G13.157x1.337 | G 1/4 | 19 | B | 13.157 | 12.907 | 12.301 | 12.051 | 11.445
16.662 |  | G16.662x1.337 | G 3/8 | 19 | A | 16.662 | 16.412 | 15.806 | 15.681 | 14.950 |  |  | 14.95 | 15.395 | 15.806 | 15.931 | 16.662 |  | 9.5250 | 33.324 | 6.5000
16.662 |  | G16.662x1.337 | G 3/8 | 19 | B | 16.662 | 16.412 | 15.806 | 15.556 | 14.950
20.955 |  | G20.955x1.814 | G 1/2 | 14 | A | 20.955 | 20.671 | 19.793 | 19.651 | 18.631 |  |  | 18.631 | 19.172 | 19.793 | 19.935 | 20.955 |  | 12.7000 | 41.910 | 8.5000
20.955 |  | G20.955x1.814 | G 1/2 | 14 | B | 20.955 | 20.671 | 19.793 | 19.509 | 18.631
22.911 |  | G22.911x1.814 | G 5/8 | 14 | A | 22.911 | 22.627 | 21.749 | 21.607 | 20.587 |  |  | 20.587 | 21.128 | 21.749 | 21.891 | 22.911 |  |  | 45.822 | 8.5000
22.911 |  | G22.911x1.814 | G 5/8 | 14 | B | 22.911 | 22.627 | 21.749 | 21.465 | 20.587
26.441 |  | G26.441x1.814 | G 3/4 | 14 | A | 26.441 | 26.157 | 25.279 | 25.137 | 24.117 |  |  | 24.117 | 24.658 | 25.279 | 25.421 | 26.441 |  | 15.8750 | 52.882 | 8.5000
26.441 |  | G26.441x1.814 | G 3/4 | 14 | B | 26.441 | 26.157 | 25.279 | 24.995 | 24.117
30.201 |  | G30.201x1.814 | G 7/8 | 14 | A | 30.201 | 29.917 | 29.039 | 28.897 | 27.877 |  |  | 27.877 | 28.418 | 29.039 | 29.181 | 30.201 |  | 22.2250 | 60.402 | 8.8000
30.201 |  | G30.201x1.814 | G 7/8 | 14 | B | 30.201 | 29.917 | 29.039 | 28.755 | 27.877
33.249 |  | G33.249x2.309 | G 1 | 11 | A | 33.249 | 32.889 | 31.770 | 31.590 | 30.291 |  |  | 30.291 | 30.931 | 31.77 | 31.95 | 33.249 |  | 25.4000 | 66.498 | 10.0000
33.249 |  | G33.249x2.309 | G 1 | 11 | B | 33.249 | 32.889 | 31.770 | 31.410 | 30.291
37.897 |  | G37.897x2.309 | G 1 1/8 | 11 | A | 37.897 | 37.537 | 36.418 | 36.238 | 34.939 |  |  | 34.939 | 35.579 | 36.418 | 36.598 | 37.897 |  | 28.5750 | 75.794 | 10.0000
37.897 |  | G37.897x2.309 | G 1 1/8 | 11 | B | 37.897 | 37.537 | 36.418 | 36.058 | 34.939
41.910 |  | G41.91x2.309 | G 1 1/4 | 11 | A | 41.910 | 41.550 | 40.431 | 40.251 | 38.952 |  |  | 38.952 | 39.592 | 40.431 | 40.611 | 41.910 |  | 31.7500 | 83.820 | 10.0000
41.910 |  | G41.91x2.309 | G 1 1/4 | 11 | B | 41.910 | 41.550 | 40.431 | 40.071 | 38.952
47.803 |  | G47.803x2.309 | G 1 1/2 | 11 | A | 47.803 | 47.443 | 46.324 | 46.144 | 44.845 |  |  | 44.845 | 45.485 | 46.324 | 46.504 | 47.803 |  | 38.1000 | 95.606 | 10.0000
47.803 |  | G47.803x2.309 | G 1 1/2 | 11 | B | 47.803 | 47.443 | 46.324 | 45.964 | 44.845
53.746 |  | G53.746x2.309 | G 1 3/4 | 11 | A | 53.746 | 53.386 | 52.267 | 52.087 | 50.788 |  |  | 50.788 | 51.428 | 52.267 | 52.447 | 53.746 |  | 44.4500 | 107.492 | 10.0000
53.746 |  | G53.746x2.309 | G 1 3/4 | 11 | B | 53.746 | 53.386 | 52.267 | 51.907 | 50.788
59.614 |  | G59.614x2.309 | G 2 | 11 | A | 59.614 | 59.254 | 58.135 | 57.955 | 56.656 |  |  | 56.656 | 57.296 | 58.135 | 58.315 | 59.614 |  | 50.8000 | 119.228 | 10.0000
59.614 |  | G59.614x2.309 | G 2 | 11 | B | 59.614 | 59.254 | 58.135 | 57.775 | 56.656
65.710 |  | G65.71x2.309 | G 2 1/4 | 11 | A | 65.710 | 65.276 | 64.231 | 64.014 | 62.752 |  |  | 62.752 | 63.392 | 64.231 | 64.448 | 65.710 |  | 57.1500 | 131.420 | 10.0000
65.710 |  | G65.71x2.309 | G 2 1/4 | 11 | B | 65.710 | 65.276 | 64.231 | 63.797 | 62.752
75.184 |  | G75.184x2.309 | G 2 1/2 | 11 | A | 75.184 | 74.750 | 73.705 | 73.488 | 72.226 |  |  | 72.226 | 72.866 | 73.705 | 73.922 | 75.184 |  |  | 150.368 | 10.0000
75.184 |  | G75.184x2.309 | G 2 1/2 | 11 | B | 75.184 | 74.750 | 73.705 | 73.271 | 72.226
81.534 |  | G81.534x2.309 | G 2 3/4 | 11 | A | 81.534 | 81.100 | 80.055 | 79.838 | 78.576 |  |  | 78.576 | 79.216 | 80.055 | 80.272 | 81.534 |  | 69.8500 | 163.068 | 10.0000
81.534 |  | G81.534x2.309 | G 2 3/4 | 11 | B | 81.534 | 81.100 | 80.055 | 79.621 | 78.576
87.884 |  | G87.884x2.309 | G 3 | 11 | A | 87.884 | 87.450 | 86.405 | 86.188 | 84.926 |  |  | 84.926 | 85.566 | 86.405 | 86.622 | 87.884 |  | 76.2000 | 175.768 | 10.0000
87.884 |  | G87.884x2.309 | G 3 | 11 | B | 87.884 | 87.450 | 86.405 | 85.971 | 84.926
100.330 |  | G100.33x2.309 | G 3 1/2 | 11 | A | 100.330 | 99.896 | 98.851 | 98.634 | 97.372 |  |  | 97.372 | 98.012 | 98.851 | 99.068 | 100.330 |  | 88.9000 | 200.660 | 10.0000
100.330 |  | G100.33x2.309 | G 3 1/2 | 11 | B | 100.330 | 99.896 | 98.851 | 98.417 | 97.372
113.030 |  | G113.03x2.309 | G 4 | 11 | A | 113.030 | 112.596 | 111.551 | 111.334 | 110.072 |  |  | 110.072 | 110.712 | 111.551 | 111.768 | 113.030 |  | 101.6000 | 226.060 | 10.0000
113.030 |  | G113.03x2.309 | G 4 | 11 | B | 113.030 | 112.596 | 111.551 | 111.117 | 110.072
125.730 |  | G125.73x2.309 | G 4 1/2 | 11 | A | 125.730 | 125.296 | 124.251 | 124.034 | 122.772 |  |  | 122.772 | 123.412 | 124.251 | 124.468 | 125.730 |  | 114.3000 | 251.460 | 10.0000
125.730 |  | G125.73x2.309 | G 4 1/2 | 11 | B | 125.730 | 125.296 | 124.251 | 123.817 | 122.772
138.430 |  | G138.43x2.309 | G 5 | 11 | A | 138.430 | 137.996 | 136.951 | 136.734 | 135.472 |  |  | 135.472 | 136.112 | 136.951 | 137.168 | 138.430 |  | 127.0000 | 276.860 | 10.0000
138.430 |  | G138.43x2.309 | G 5 | 11 | B | 138.430 | 137.996 | 136.951 | 136.517 | 135.472
151.130 |  | G151.13x2.309 | G 5 1/2 | 11 | A | 151.130 | 150.696 | 149.651 | 149.434 | 148.172 |  |  | 148.172 | 148.812 | 149.651 | 149.868 | 151.130 |  | 139.7000 | 302.260 | 10.0000
151.130 |  | G151.13x2.309 | G 5 1/2 | 11 | B | 151.130 | 150.696 | 149.651 | 149.217 | 148.172
163.830 |  | G163.83x2.309 | G 6 | 11 | A | 163.830 | 163.396 | 162.351 | 162.134 | 160.872 |  |  | 160.872 | 161.512 | 162.351 | 162.568 | 163.830 |  | 152.4000 | 327.660 | 10.0000
163.830 |  | G163.83x2.309 | G 6 | 11 | B | 163.830 | 163.396 | 162.351 | 161.917 | 160.872

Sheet: DIN Pipe Threads
M Q | DIN-Rohrgewinde |  | Sort Order - 18 |  | External |  |  |  |  |  |  | Internal
 |  |  |  |  |  | Major Dia |  | Pitch Dia |  | Minor Dia |  |  | Minor Dia |  | Pitch Dia |  | Major Dia |  | Tap Drill | Thread Depth | Thread Runouts
Size | Size Suffix | Thread Designation | Custom Thread Designation | TPI | Class | Max | Min | Max | Min | Max | Min | Class | Min | Max | Min | Max | Min | Max | Basic
7.723 |  | G7.723x0.907 | G 1/16 | 28 | A | 7.723 | 7.509 | 7.142 | 7.035 | 6.561 |  |  | 6.561 | 6.834 | 7.142 | 7.249 | 7.723 |  | 1.5875 | 15.446 | 4.5000
7.723 |  | G7.723x0.907 | G 1/16 | 28 | B | 7.723 | 7.509 | 7.142 | 6.928 | 6.561
9.728 |  | G9.728x0.907 | G 1/8 | 28 | A | 9.728 | 9.514 | 9.147 | 9.040 | 8.566 |  |  | 8.566 | 8.848 | 9.147 | 9.254 | 9.728 |  | 3.1750 | 19.456 | 4.5000
9.728 |  | G9.728x0.907 | G 1/8 | 28 | B | 9.728 | 9.514 | 9.147 | 8.933 | 8.566
13.157 |  | G13.157x1.337 | G 1/4 | 19 | A | 13.157 | 12.907 | 12.301 | 12.176 | 11.445 |  |  | 11.445 | 11.89 | 12.301 | 12.426 | 13.157 |  | 6.3500 | 26.314 | 6.5000
13.157 |  | G13.157x1.337 | G 1/4 | 19 | B | 13.157 | 12.907 | 12.301 | 12.051 | 11.445
16.662 |  | G16.662x1.337 | G 3/8 | 19 | A | 16.662 | 16.412 | 15.806 | 15.681 | 14.950 |  |  | 14.95 | 15.395 | 15.806 | 15.931 | 16.662 |  | 9.5250 | 33.324 | 6.5000
16.662 |  | G16.662x1.337 | G 3/8 | 19 | B | 16.662 | 16.412 | 15.806 | 15.556 | 14.950
20.955 |  | G20.955x1.814 | G 1/2 | 14 | A | 20.955 | 20.671 | 19.793 | 19.651 | 18.631 |  |  | 18.631 | 19.172 | 19.793 | 19.935 | 20.955 |  | 12.7000 | 41.910 | 8.5000
20.955 |  | G20.955x1.814 | G 1/2 | 14 | B | 20.955 | 20.671 | 19.793 | 19.509 | 18.631
22.911 |  | G22.911x1.814 | G 5/8 | 14 | A | 22.911 | 22.627 | 21.749 | 21.607 | 20.587 |  |  | 20.587 | 21.128 | 21.749 | 21.891 | 22.911 |  |  | 45.822 | 8.5000
22.911 |  | G22.911x1.814 | G 5/8 | 14 | B | 22.911 | 22.627 | 21.749 | 21.465 | 20.587
26.441 |  | G26.441x1.814 | G 3/4 | 14 | A | 26.441 | 26.157 | 25.279 | 25.137 | 24.117 |  |  | 24.117 | 24.658 | 25.279 | 25.421 | 26.441 |  | 15.8750 | 52.882 | 8.5000
26.441 |  | G26.441x1.814 | G 3/4 | 14 | B | 26.441 | 26.157 | 25.279 | 24.995 | 24.117
30.201 |  | G30.201x1.814 | G 7/8 | 14 | A | 30.201 | 29.917 | 29.039 | 28.897 | 27.877 |  |  | 27.877 | 28.418 | 29.039 | 29.181 | 30.201 |  | 22.2250 | 60.402 | 8.5000
30.201 |  | G30.201x1.814 | G 7/8 | 14 | B | 30.201 | 29.917 | 29.039 | 28.755 | 27.877
33.249 |  | G33.249x2.309 | G 1 | 11 | A | 33.249 | 32.889 | 31.770 | 31.590 | 30.291 |  |  | 30.291 | 30.931 | 31.77 | 31.95 | 33.249 |  | 25.4000 | 66.498 | 10.5000
33.249 |  | G33.249x2.309 | G 1 | 11 | B | 33.249 | 32.889 | 31.770 | 31.410 | 30.291
37.897 |  | G37.897x2.309 | G 1 1/8 | 11 | A | 37.897 | 37.537 | 36.418 | 36.238 | 34.939 |  |  | 34.939 | 35.579 | 36.418 | 36.598 | 37.897 |  | 28.5750 | 75.794 | 10.5000
37.897 |  | G37.897x2.309 | G 1 1/8 | 11 | B | 37.897 | 37.537 | 36.418 | 36.058 | 34.939
41.910 |  | G41.91x2.309 | G 1 1/4 | 11 | A | 41.910 | 41.550 | 40.431 | 40.251 | 38.952 |  |  | 38.952 | 39.592 | 40.431 | 40.611 | 41.910 |  | 31.7500 | 83.820 | 10.5000
41.910 |  | G41.91x2.309 | G 1 1/4 | 11 | B | 41.910 | 41.550 | 40.431 | 40.071 | 38.952
47.803 |  | G47.803x2.309 | G 1 1/2 | 11 | A | 47.803 | 47.443 | 46.324 | 46.144 | 44.845 |  |  | 44.845 | 45.485 | 46.324 | 46.504 | 47.803 |  | 38.1000 | 95.606 | 10.5000
47.803 |  | G47.803x2.309 | G 1 1/2 | 11 | B | 47.803 | 47.443 | 46.324 | 45.964 | 44.845
53.746 |  | G53.746x2.309 | G 1 3/4 | 11 | A | 53.746 | 53.386 | 52.267 | 52.087 | 50.788 |  |  | 50.788 | 51.428 | 52.267 | 52.447 | 53.746 |  | 44.4500 | 107.492 | 10.5000
53.746 |  | G53.746x2.309 | G 1 3/4 | 11 | B | 53.746 | 53.386 | 52.267 | 51.907 | 50.788
59.614 |  | G59.614x2.309 | G 2 | 11 | A | 59.614 | 59.254 | 58.135 | 57.955 | 56.656 |  |  | 56.656 | 57.296 | 58.135 | 58.315 | 59.614 |  | 50.8000 | 119.228 | 10.5000
59.614 |  | G59.614x2.309 | G 2 | 11 | B | 59.614 | 59.254 | 58.135 | 57.775 | 56.656
65.710 |  | G65.71x2.309 | G 2 1/4 | 11 | A | 65.710 | 65.276 | 64.231 | 64.014 | 62.752 |  |  | 62.752 | 63.392 | 64.231 | 64.448 | 65.710 |  | 57.1500 | 131.420 | 10.5000
65.710 |  | G65.71x2.309 | G 2 1/4 | 11 | B | 65.710 | 65.276 | 64.231 | 63.797 | 62.752
75.184 |  | G75.184x2.309 | G 2 1/2 | 11 | A | 75.184 | 74.750 | 73.705 | 73.488 | 72.226 |  |  | 72.226 | 72.866 | 73.705 | 73.922 | 75.184 |  |  | 150.368 | 10.5000
75.184 |  | G75.184x2.309 | G 2 1/2 | 11 | B | 75.184 | 74.750 | 73.705 | 73.271 | 72.226
81.534 |  | G81.534x2.309 | G 2 3/4 | 11 | A | 81.534 | 81.100 | 80.055 | 79.838 | 78.576 |  |  | 78.576 | 79.216 | 80.055 | 80.272 | 81.534 |  | 69.8500 | 163.068 | 10.5000
81.534 |  | G81.534x2.309 | G 2 3/4 | 11 | B | 81.534 | 81.100 | 80.055 | 79.621 | 78.576
87.884 |  | G87.884x2.309 | G 3 | 11 | A | 87.884 | 87.450 | 86.405 | 86.188 | 84.926 |  |  | 84.926 | 85.566 | 86.405 | 86.622 | 87.884 |  | 76.2000 | 175.768 | 10.5000
87.884 |  | G87.884x2.309 | G 3 | 11 | B | 87.884 | 87.450 | 86.405 | 85.971 | 84.926
100.330 |  | G100.33x2.309 | G 3 1/2 | 11 | A | 100.330 | 99.896 | 98.851 | 98.634 | 97.372 |  |  | 97.372 | 98.012 | 98.851 | 99.068 | 100.330 |  | 88.9000 | 200.660 | 10.5000
100.330 |  | G100.33x2.309 | G 3 1/2 | 11 | B | 100.330 | 99.896 | 98.851 | 98.417 | 97.372
113.030 |  | G113.03x2.309 | G 4 | 11 | A | 113.030 | 112.596 | 111.551 | 111.334 | 110.072 |  |  | 110.072 | 110.712 | 111.551 | 111.768 | 113.030 |  | 101.6000 | 226.060 | 10.5000
113.030 |  | G113.03x2.309 | G 4 | 11 | B | 113.030 | 112.596 | 111.551 | 111.117 | 110.072
125.730 |  | G125.73x2.309 | G 4 1/2 | 11 | A | 125.730 | 125.296 | 124.251 | 124.034 | 122.772 |  |  | 122.772 | 123.412 | 124.251 | 124.468 | 125.730 |  | 114.3000 | 251.460 | 10.5000
125.730 |  | G125.73x2.309 | G 4 1/2 | 11 | B | 125.730 | 125.296 | 124.251 | 123.817 | 122.772
138.430 |  | G138.43x2.309 | G 5 | 11 | A | 138.430 | 137.996 | 136.951 | 136.734 | 135.472 |  |  | 135.472 | 136.112 | 136.951 | 137.168 | 138.430 |  | 127.0000 | 276.860 | 10.5000
138.430 |  | G138.43x2.309 | G 5 | 11 | B | 138.430 | 137.996 | 136.951 | 136.517 | 135.472
151.130 |  | G151.13x2.309 | G 5 1/2 | 11 | A | 151.130 | 150.696 | 149.651 | 149.434 | 148.172 |  |  | 148.172 | 148.812 | 149.651 | 149.868 | 151.130 |  | 139.7000 | 302.260 | 10.5000
151.130 |  | G151.13x2.309 | G 5 1/2 | 11 | B | 151.130 | 150.696 | 149.651 | 149.217 | 148.172
163.830 |  | G163.83x2.309 | G 6 | 11 | A | 163.830 | 163.396 | 162.351 | 162.134 | 160.872 |  |  | 160.872 | 161.512 | 162.351 | 162.568 | 163.830 |  | 152.4000 | 327.660 | 10.5000
163.830 |  | G163.83x2.309 | G 6 | 11 | B | 163.830 | 163.396 | 162.351 | 161.917 | 160.872

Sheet: BSP Pipe Threads
M Q | BSP-Rohrgewinde |  | Sort Order - 19 |  | External |  |  |  |  |  |  | Internal
 |  |  |  |  |  | Major Dia |  | Pitch Dia |  | Minor Dia |  |  | Minor Dia |  | Pitch Dia |  | Major Dia |  | Tap Drill | Thread Depth | Thread Runouts
Size | Size Suffix | Thread Designation | Custom Thread Designation | TPI | Class | Max | Min | Max | Min | Max | Min | Class | Min | Max | Min | Max | Min | Max | Basic |  | Basic
1/16 |  | G 1/16-28 | G 1/16-28 | 28 | A | 7.723 | 7.509 | 7.142 | 7.035 | 6.561 |  |  | 6.561 | 6.834 | 7.142 | 7.249 | 7.723 |  | 6.6000 | 15.4460 | 4.5000
1/16 |  | G 1/16-28 | G 1/16-28 | 28 | B | 7.723 | 7.509 | 7.142 | 7.035 | 6.561
1/8 |  | G 1/8-28 | G 1/8-28 | 28 | A | 9.728 | 9.514 | 9.147 | 9.040 | 8.566 |  |  | 8.566 | 8.848 | 9.147 | 9.254 | 9.728 |  | 8.7300 | 19.4560 | 4.5000
1/8 |  | G 1/8-28 | G 1/8-28 | 28 | B | 9.728 | 9.514 | 9.147 | 9.040 | 8.566
1/4 |  | G 1/4-19 | G 1/4-19 | 19 | A | 13.157 | 12.907 | 12.301 | 12.176 | 11.445 |  |  | 11.445 | 11.89 | 12.301 | 12.426 | 13.157 |  | 11.8000 | 26.3140 | 6.5000
1/4 |  | G 1/4-19 | G 1/4-19 | 19 | B | 13.157 | 12.907 | 12.301 | 12.176 | 11.445
3/8 |  | G 3/8-19 | G 3/8-19 | 19 | A | 16.662 | 16.412 | 15.806 | 15.681 | 14.950 |  |  | 14.95 | 15.395 | 15.806 | 15.931 | 16.662 |  | 15.2500 | 33.3240 | 6.5000
3/8 |  | G 3/8-19 | G 3/8-19 | 19 | B | 16.662 | 16.412 | 15.806 | 15.681 | 14.950
1/2 |  | G 1/2-14 | G 1/2-14 | 14 | A | 20.955 | 20.671 | 19.793 | 19.651 | 18.631 |  |  | 18.631 | 19.172 | 19.793 | 19.935 | 20.955 |  | 19.0500 | 41.9100 | 8.5000
1/2 |  | G 1/2-14 | G 1/2-14 | 14 | B | 20.955 | 20.671 | 19.793 | 19.651 | 18.631
5/8 |  | G 5/8-14 | G 5/8-14 | 14 | A | 22.911 | 22.627 | 21.749 | 21.607 | 20.587 |  |  | 20.587 | 21.128 | 21.749 | 21.891 | 22.911 |  | 21.0000 | 45.8220 | 8.5000
5/8 |  | G 5/8-14 | G 5/8-14 | 14 | B | 22.911 | 22.627 | 21.749 | 21.607 | 20.587
3/4 |  | G 3/4-14 | G 3/4-14 | 14 | A | 26.441 | 26.157 | 25.279 | 25.137 | 24.117 |  |  | 24.117 | 24.658 | 25.279 | 25.421 | 26.441 |  | 24.5000 | 52.8820 | 8.5000
3/4 |  | G 3/4-14 | G 3/4-14 | 14 | B | 26.441 | 26.157 | 25.279 | 25.137 | 24.117
7/8 |  | G 7/8-14 | G 7/8-14 | 14 | A | 30.201 | 29.917 | 29.039 | 28.897 | 27.877 |  |  | 27.877 | 28.418 | 29.039 | 29.181 | 30.201 |  | 28.2500 | 60.4020 | 8.5000
7/8 |  | G 7/8-14 | G 7/8-14 | 14 | B | 30.201 | 29.917 | 29.039 | 28.897 | 27.877
1 |  | G 1-11 | G 1-11 | 11 | A | 33.249 | 32.889 | 31.770 | 31.590 | 30.291 |  |  | 30.291 | 30.931 | 31.77 | 31.95 | 33.249 |  | 30.7500 | 66.4980 | 10.0000
1 |  | G 1-11 | G 1-11 | 11 | B | 33.249 | 32.889 | 31.770 | 31.590 | 30.291
1 1/4 |  | G 1 1/4-11 | G 1 1/4-11 | 11 | A | 41.910 | 41.550 | 40.431 | 40.251 | 38.952 |  |  | 38.952 | 39.592 | 40.431 | 40.611 | 41.910 |  | 39.5000 | 83.8200 | 10.0000
1 1/4 |  | G 1 1/4-11 | G 1 1/4-11 | 11 | B | 41.910 | 41.550 | 40.431 | 40.251 | 38.952
1 1/2 |  | G 1 1/2-11 | G 1 1/2-11 | 11 | A | 47.803 | 47.443 | 46.324 | 46.144 | 44.845 |  |  | 44.845 | 45.485 | 46.324 | 46.504 | 47.803 |  | 45.5000 | 95.6060 | 10.0000
1 1/2 |  | G 1 1/2-11 | G 1 1/2-11 | 11 | B | 47.803 | 47.443 | 46.324 | 46.144 | 44.845
1 3/4 |  | G 1 3/4-11 | G 1 3/4-11 | 11 | A | 53.746 | 53.386 | 52.267 | 52.087 | 50.788 |  |  | 50.788 | 51.428 | 52.267 | 52.447 | 53.746 |  | 51.0000 | 107.4920 | 10.0000
1 3/4 |  | G 1 3/4-11 | G 1 3/4-11 | 11 | B | 53.746 | 53.386 | 52.267 | 52.087 | 50.788
2 |  | G 2-11 | G 2-11 | 11 | A | 59.614 | 59.254 | 58.135 | 57.955 | 56.656 |  |  | 56.656 | 57.296 | 58.135 | 58.315 | 59.614 |  | 57.0000 | 119.2280 | 10.0000
2 |  | G 2-11 | G 2-11 | 11 | B | 59.614 | 59.254 | 58.135 | 57.955 | 56.656
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

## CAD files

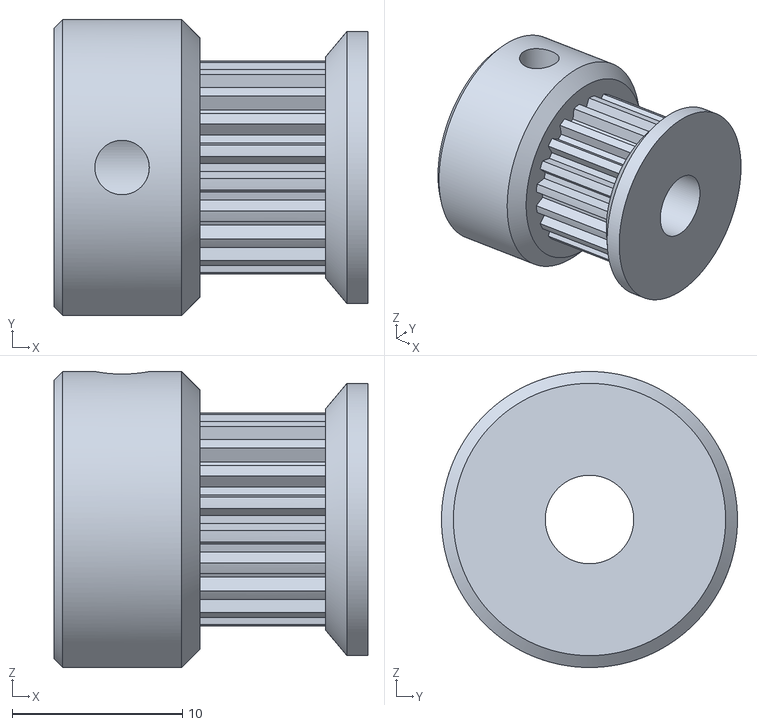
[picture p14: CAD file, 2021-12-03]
STL/Assembly_XYTable_Aliepexress_00_XYTable_pulley_28.stl
18.5 x 17.4 x 17.4

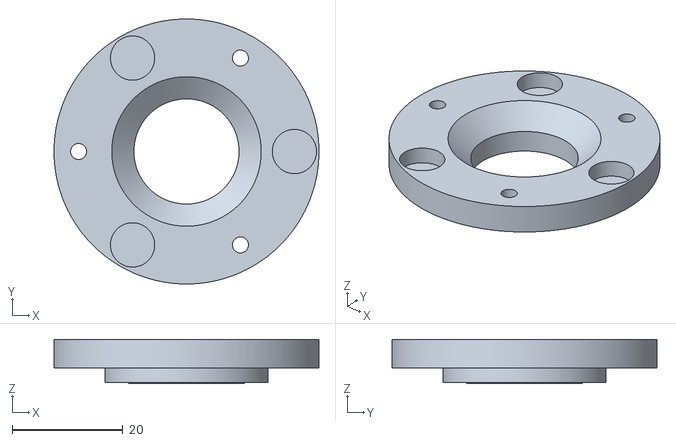
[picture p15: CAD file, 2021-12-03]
STL/Assembly_XYTable_Aliepexress_01_SMLM_Holder_Base_34.stl
47.9 x 47.9 x 8.00

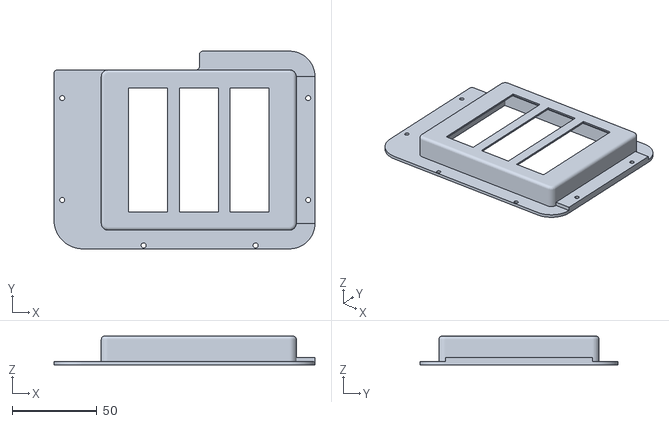
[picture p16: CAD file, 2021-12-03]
STL/Assembly_XYTable_Aliepexress_30_XYTable_Aliexpress_sampleinsert_3.stl
153.8 x 116.5 x 17.0

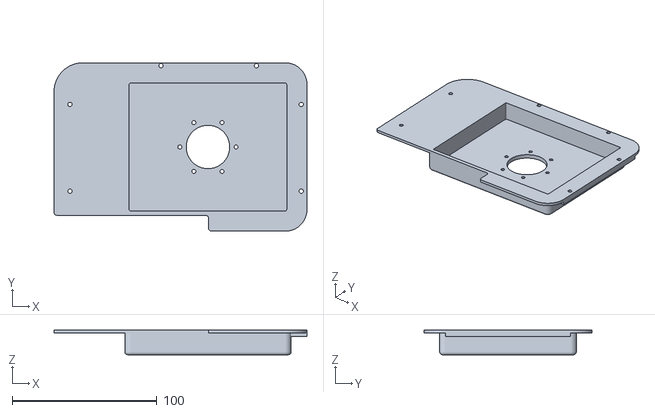
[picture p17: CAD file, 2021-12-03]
STL/Assembly_XYTable_Aliepexress_30_XYTable_Aliexpress_sampleinsert_round_31.stl
175.0 x 116.5 x 17.0

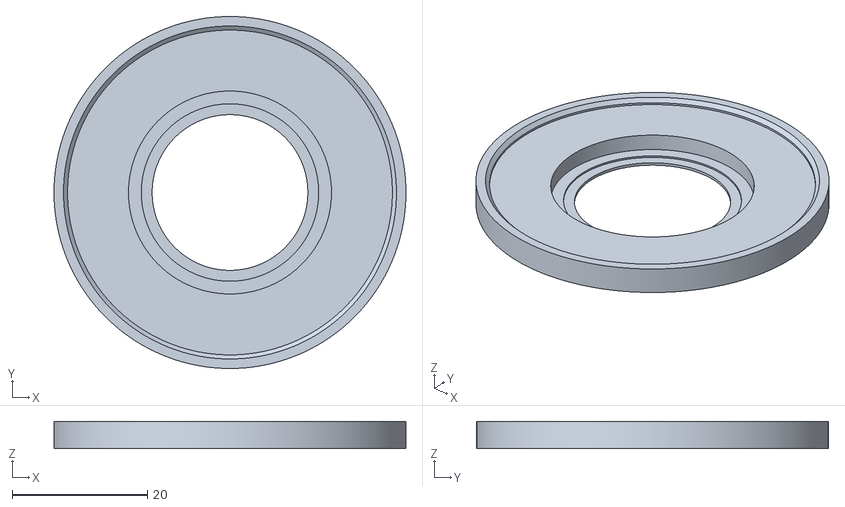
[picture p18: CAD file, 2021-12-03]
STL/Assembly_XYTable_Aliepexress_02_SMLM_Holdre_Bottom_35.stl
52.0 x 52.0 x 4.00

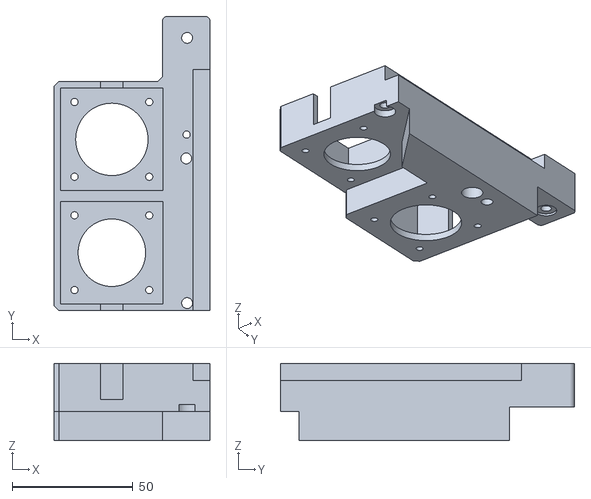
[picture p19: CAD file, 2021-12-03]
STL/Assembly_XYTable_Aliepexress_30_XYTable_Aliexpress_motormount_4.stl
64.7 x 122.0 x 32.0

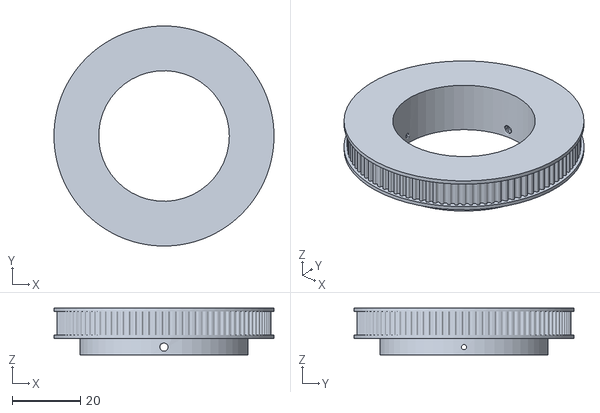
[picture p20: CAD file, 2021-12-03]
STL/Assembly_XYTable_Aliepexress_00_XYTable_large_gear_29.stl
64.7 x 64.7 x 13.8

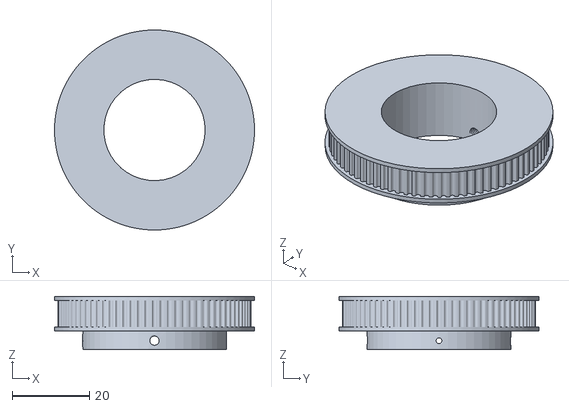
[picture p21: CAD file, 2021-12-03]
STL/Assembly_XYTable_Aliepexress_00_XYTable_medium_gear_27.stl
51.9 x 51.9 x 13.8

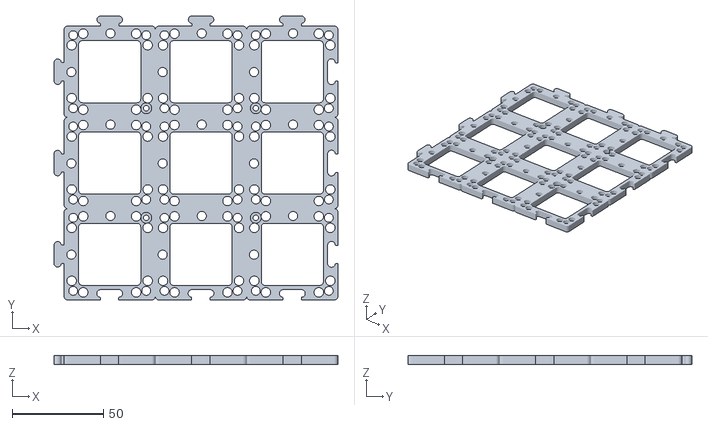
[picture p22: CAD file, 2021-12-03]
STL/Assembly_XYTable_Aliepexress_30_XYTabel_Aliexpress_basplateadapter_2.stl
155.5 x 155.5 x 5.00

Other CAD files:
STL/Assembly_XYTable_Aliepexress_00_XYTable_pulley_30.stl
INVENTOR/Templates/English/ANSI (in).dwg
INVENTOR/Templates/Metric/JIS.dwg
INVENTOR/Templates/Standard.dwg
INVENTOR/Templates/Metric/BSI.dwg
INVENTOR/Templates/Metric/ISO.dwg
INVENTOR/Templates/Metric/ANSI (mm).dwg
INVENTOR/Templates/Metric/GOST.dwg
INVENTOR/Templates/Metric/DIN.dwg
INVENTOR/Design Data/AIT/Mold Design/mold design stop pin.ipt
INVENTOR/Design Data/Cable & Harness/de-DE/harness.iam
INVENTOR/Design Data/Cable & Harness/en-US/harness.iam
INVENTOR/Design Data/Tube & Pipe/de-DE/piping runs.iam
INVENTOR/Design Data/Tube & Pipe/en-US/piping runs.iam
INVENTOR/Templates/English/ANSI (in).idw
INVENTOR/Templates/English/Mold Design (in).iam
INVENTOR/Templates/English/Sheet Metal (in).ipt
INVENTOR/Templates/English/Standard (in).iam
INVENTOR/Templates/English/Standard (in).ipn
INVENTOR/Templates/English/Standard (in).ipt
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

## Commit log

2021-11-28 Updating documetation
    [30_XYTabel_Aliexpress_basplateadapter.stl, 30_XYTable_Aliexpress_motormount.stl, 30_XYTable_Aliexpress_sampleinsert.stl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]
2021-12-03 Updating parts and documentation for the stage
    [00_0-ring.ipt, 00_Coverglass_25mm.ipt, 00_NEMA17_pancake.iam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]
